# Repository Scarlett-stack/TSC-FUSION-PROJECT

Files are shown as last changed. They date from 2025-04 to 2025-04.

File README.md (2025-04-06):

# TSC-FUSION-PROJECT
Ebook project TSC 2025
## Schema bloc


## BOM
| Componentă | Link sursă | Datasheet |
|---|---|---|
| BME680 | [SnapEDA](https://www.snapeda.com/parts/BME680/Bosch/view-part/?welcome=home) | [Datasheet](https://www.snapeda.com/parts/BME680/Bosch%20Sensortec/datasheet/) |
| CC0402MRX5R5BB106 | [ComponentSearchEngine](https://componentsearchengine.com/part-view/CC0402MRX5R5BB106/YAGEO) | [Datasheet](https://componentsearchengine.com/Datasheets/2/CC0402MRX5R5BB106.pdf) |
| DMG2305UX-7 | [ComponentSearchEngine](https://componentsearchengine.com/part-view/DMG2305UX-7/Diodes%20Incorporated) | [Datasheet](https://www.diodes.com//assets/Datasheets/DMG2305UX.pdf) |
| Varistor B72520T0350K062 | [Mouser](https://www.mouser.co.uk/ProductDetail/EPCOS-TDK/B72520T0350K062?qs=dEfas%2FXlABIszF52uu7vrg%3D%3D) | [Datasheet](https://www.tdk-electronics.tdk.com/inf/75/db/CTVS_14/Surge_protection_series.pdf) |
| FH34SRJ-24S-0.5SH_99_ | [ComponentSearchEngine](https://componentsearchengine.com/part-view/XC6220A331MR-G/Torex) | [Datasheet](https://product.torexsemi.com/system/files/series/xc6220.pdf) |
| MAX17048G+T10 | [SnapEDA](https://www.snapeda.com/parts/MAX17048G+T10/Analog+Devices/view-part/?ref=eda) | [Datasheet](https://www.snapeda.com/parts/MAX17048G+T10/Analog%20Devices/datasheet/) |
| MBR0530 | [Mouser](https://ro.mouser.com/ProductDetail/KYOCERA-AVX/SD0805S020S1R0?qs=jCA%252BPfw4LHbpkAoSnwrdjw%3D%3D) | [Datasheet](https://ro.mouser.com/datasheet/2/40/schottky-3165252.pdf) |
| PGB1010603MR | [SnapEDA](https://www.snapeda.com/parts/PGB1010603MR/Littelfuse/view-part/?ref=eda) | [Datasheet](https://www.snapeda.com/parts/PGB1010603MR/Littelfuse%20Inc./datasheet/) |
| TR3B106K025C1300 | [Mouser](https://ro.mouser.com/ProductDetail/Vishay-Sprague/TR3B106K025C1300?qs=jCGqFXxTmLdffnuDkXzk1g%3D%3D) | [Datasheet](https://www.vishay.com/docs/40080/tr3.pdf) |
| USB4110-GF-A | [ComponentSearchEngine](https://componentsearchengine.com/part-view/USB4110-GF-A/GCT%20(GLOBAL%20CONNECTOR%20TECHNOLOGY)) | [Datasheet](https://gct.co/files/drawings/usb4110.pdf) |
| SI1308EDL-T1-GE3 | [ComponentSearchEngine](https://componentsearchengine.com/part-view/SI1308EDL-T1-GE3/Vishay) | [Datasheet](https://componentsearchengine.com/Datasheets/1/SI1308EDL-T1-GE3.pdf) |
| Solder Jumper (SJ) | [GrabCAD](https://grabcad.com/library/solder-jumpers-1) | — |
| USBLC6-2SC6Y | [SnapEDA](https://www.snapeda.com/parts/USBLC6-2SC6Y/STMicroelectronics/view-part/?ref=eda) | [Datasheet](https://www.snapeda.com/parts/USBLC6-2SC6Y/STMicroelectronics/datasheet/) |
| W25Q512JVEIQ | [SnapEDA](https://www.snapeda.com/parts/W25Q512JVEIQ/Winbond+Electronics/view-part/?ref=eda) | [Datasheet](https://www.snapeda.com/parts/W25Q512JVEIQ/Winbond%20Electronics/datasheet/) |
| XC6220A331MR-G | [ComponentSearchEngine](https://componentsearchengine.com/part-view/XC6220A331MR-G/Torex) | [Datasheet](https://product.torexsemi.com/system/files/series/xc6220.pdf) |
| RC0402FR-07226RL | [SnapEDA](https://www.snapeda.com/parts/RC0402FR-07226RL/Yageo/view-part/) | [Datasheet](https://www.snapeda.com/parts/RC0402FR-07226RL/Yageo/datasheet/) |
| QWIIC PRT-14417 | [SnapEDA](https://www.snapeda.com/parts/PRT-14417/SparkFun/view-part/) | [Datasheet](https://www.snapeda.com/parts/PRT-14417/SparkFun%20Electronics/datasheet/) |
| BUTTON EVQPUJ02K | [Panasonic](https://industry.panasonic.com/global/en/downloads?tab=cad&small_g_cd=203&part_no=EVQPUJ02K) | [Datasheet](https://industry.panasonic.com/global/en/downloads?tab=catalog&small_g_cd=203&part_no=EVQPUJ02K) |
| CPH3225A | [SnapEDA](https://www.snapeda.com/parts/CPH3225A/Seiko+Instruments/view-part/?ref=eda) | [Datasheet](https://www.snapeda.com/parts/CPH3225A/Seiko%20Instruments/datasheet/) |
| KP-1608SURCK (LED 0603) | [SnapEDA](https://www.snapeda.com/parts/KP-1608SURCK/Kingbright/view-part/?ref=search&t=LED%200603) | [Datasheet](https://www.snapeda.com/parts/KP-1608SURCK/Kingbright/datasheet/) |
| 112A-TAAR-R03_ATTEND | [Comet](https://store.comet.bg/en/Catalogue/Product/43497/) | [Datasheet](https://store.comet.bg/en/Catalogue/Product/43497/) |
| 744043680 | [DigiKey](https://www.digikey.sg/en/models/1638515) | [Datasheet](https://www.we-online.com/components/products/datasheet/744043680.pdf) |
| BD5229G-TR | [ComponentSearchEngine](https://componentsearchengine.com/part-view/BD5229G-TR/ROHM%20Semiconductor) | [Datasheet](https://datasheet.datasheetarchive.com/originals/distributors/Datasheets_SAMA/f2b9741ef86007909f138d561a359946.pdf) |
| DS3231SN# | [SnapEDA](https://www.snapeda.com/parts/DS3231SN%23/Analog+Devices/view-part/?ref=eda) | [Datasheet](https://www.snapeda.com/parts/DS3231SN%23/Analog%20Devices/datasheet/) |
| ESP32-C6-WROOM-1-N8 | [SnapEDA](https://www.snapeda.com/parts/ESP32-C6-WROOM-1-N8/Espressif+Systems/view-part/?ref=eda) | [Datasheet](https://www.snapeda.com/parts/ESP32-C6-WROOM-1-N8/Espressif%20Systems/datasheet/) |
| MCP73831 | [DigiKey](https://www.digikey.com/en/models/1874108) | — |
## Conexiuni ESP32-C6

| Funcționalitate | Pin ESP32-C6 | Descriere |
|---|---|---|
| UART pentru debug | TX/RX | Conectat la USB pentru programare si debug |
| I2C | IO4 (SCL), IO5 (SDA) | Utilizat pentru BME680, RTC și Qwiic connector |
| SPI | IO10 (CLK), IO11 (MOSI), IO12 (MISO), IO13 (CS) | Conexiune la memorie flash și display e-paper |
| Buton BOOT | IO9 | Conectat la reset/supervisor |
| LED / Status | IO6 | Indicator vizual |
| GPIO-uri libere | IO0, IO1, IO2, IO3 | Disponibile pentru extensii |

---

## Alimentare și Management Energie

- Alimentare principala: **3.7V Li-Po**
- Convertor LDO: **DMG2305UX** + **XC6220A331MR-G** — iesire 3.3V/300mA
- incarcare baterie: **MCP73831**
- Monitorizare baterie: **MAX17048**
- Protectie ESD: **USBLC6-2SC6Y** si protectii dedicate SPI

---

## Funcționalitate Hardware

- **ESP32-C6**: Procesor principal, suport Wi-Fi și BLE, interfata pentru toate componentele externe.
- **E-paper display**: Consum redusă.
- **Senzor de mediu BME680**: Citiri de temperatura, umiditate și calitate aer.
- **DS3231SN**: Ceas de timp real cu baterie de rezerva.
- **Memorie externă W25Q512JVEIQ**: 64MB pentru carti, setari etc.
- **MAX17048**: Estimare precisa a nivelului bateriei.
- **Interfete QWIIC / SPI / I2C** pentru extensibilitate și modularitate.

---

## Imagini PCB

Vezi folderul Images pt detalii

---

## Alte observații

- PCB-ul este în format Eagle, dimensiune compactă
- Conector USB-C cu protecții ESD
- Buton BOOT și RESET integrate
- Jumperi pentru configurare de test/debug
- Test Pads pentru depanare rapida

---
Am acceptat erorile SMD de overlap pt ca asa ni s-a zis la curs

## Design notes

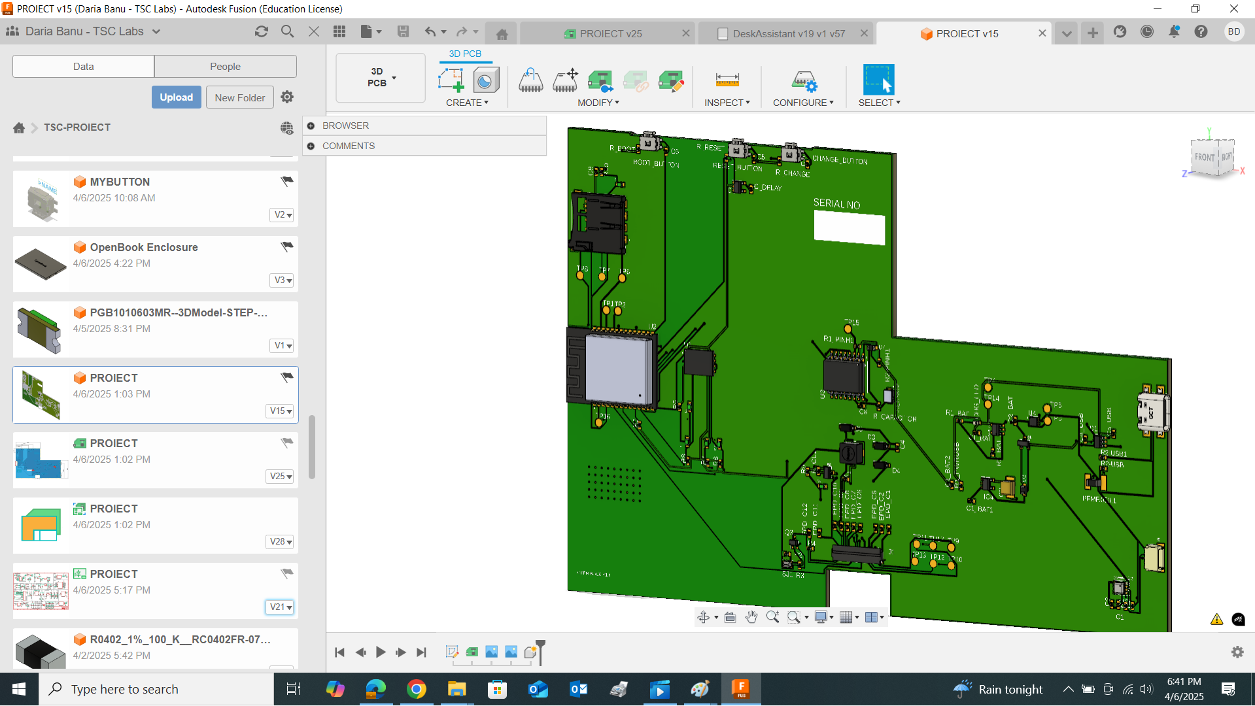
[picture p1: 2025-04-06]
Images/pcb-3d.png

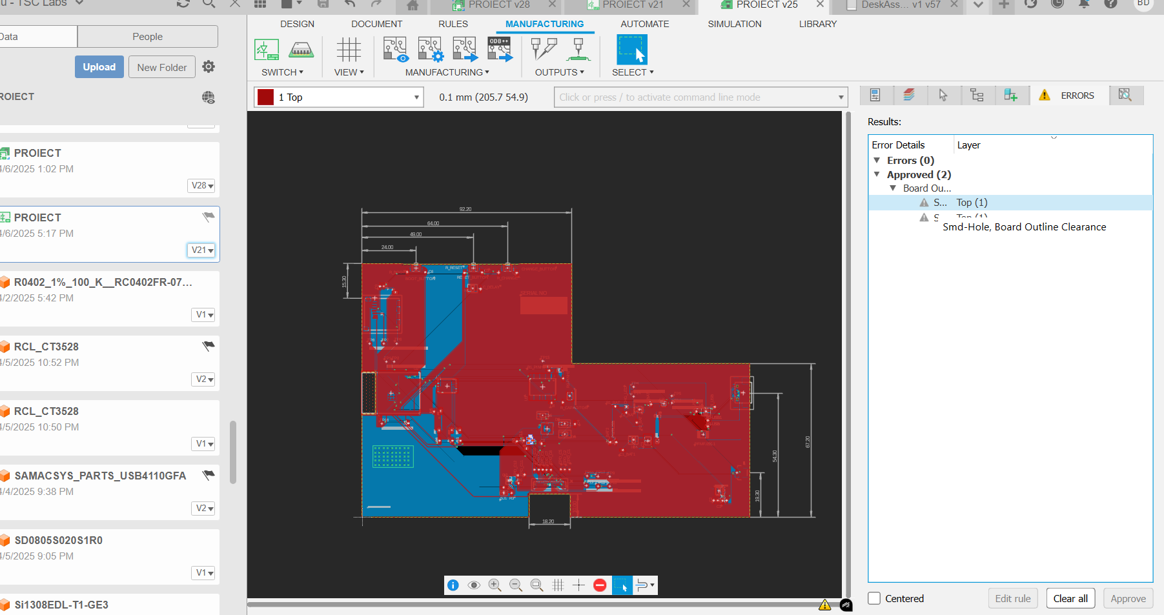
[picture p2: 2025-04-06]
Images/pcb-plan-masa.png

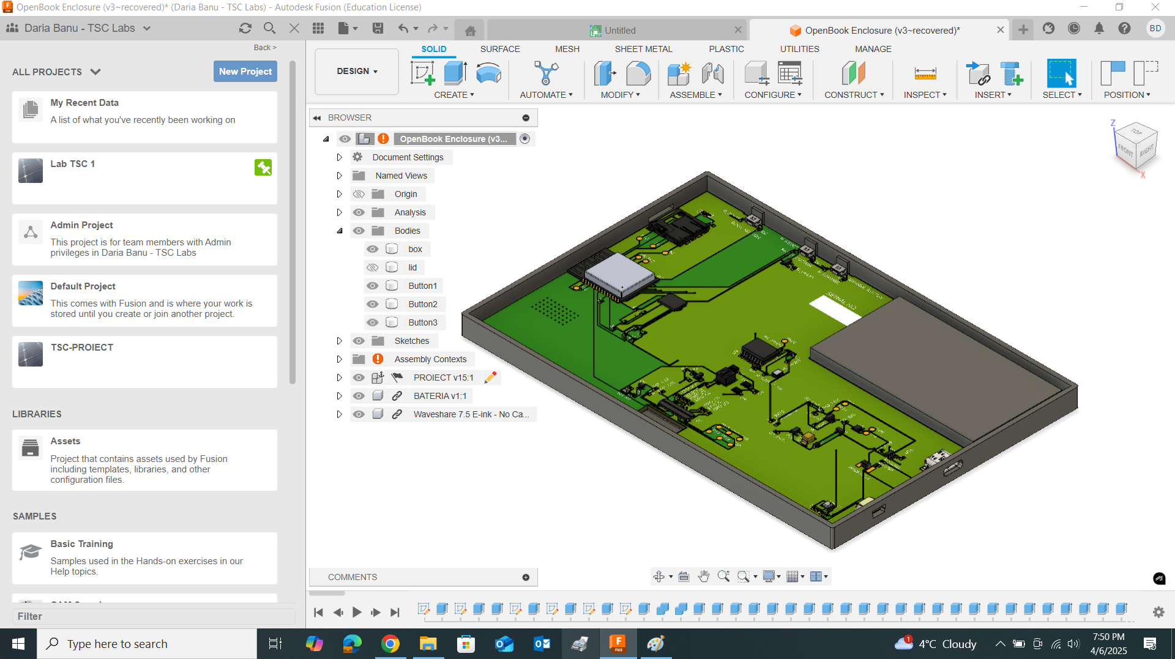
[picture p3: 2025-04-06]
Images/pcb-in-carcasa.png

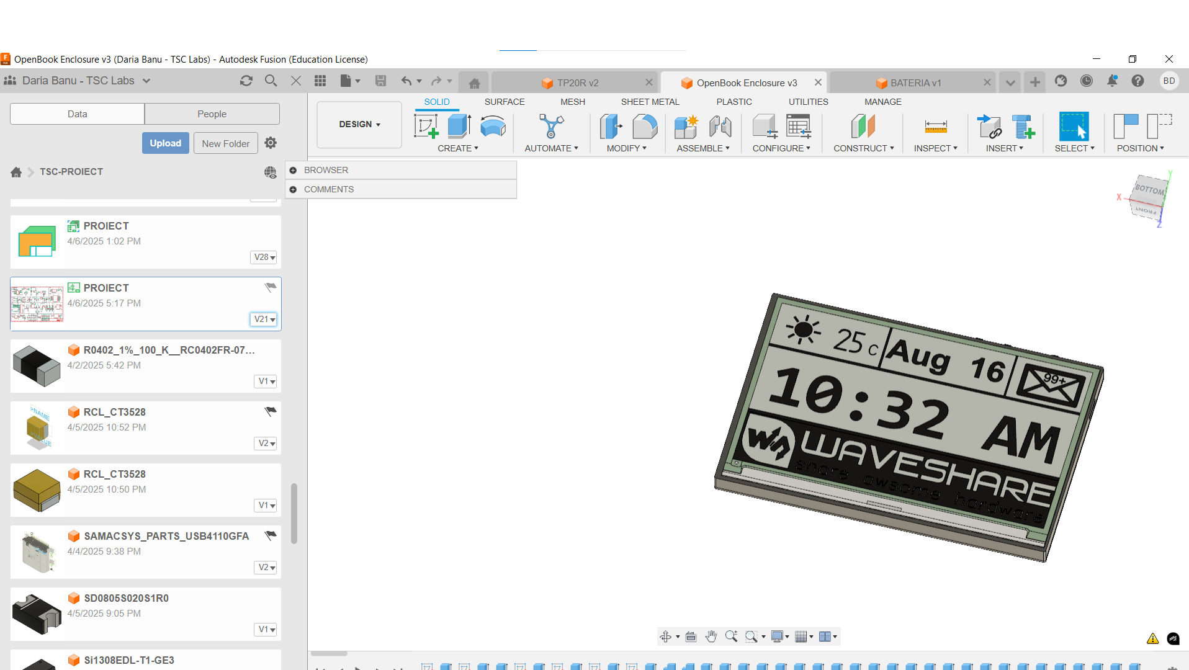
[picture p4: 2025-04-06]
Images/final_ebookreader.png

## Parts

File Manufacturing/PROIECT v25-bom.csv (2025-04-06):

Qty | Value | Device | Package | Parts | Description | ARROW_PART_NUMBER | ARROW_PRICE-STOCK | AVAILABILITY | CHECK_PRICES | DESCRIPTION | HEIGHT | MANUFACTURER_NAME | MANUFACTURER_PART_NUMBER | MF | MOUSER_PART_NUMBER | MOUSER_PRICE-STOCK | MOUSER_TESTING_PART_NUMBER | MOUSER_TESTING_PRICE-STOCK | MP | NUME | PACKAGE | PRICE | Q2 | SNAPEDA_LINK
1 |  | ADAFRUIT_LEDCHIP-LED0603 | ADAFRUIT_CHIP-LED0603 | CHG_LED | LED
1 |  | SJ. | SJ | SJ1 | SMD solder JUMPER
1 | 0.1uF/50V | EAGLE-LTSPICE_CC0402 | EAGLE-LTSPICE_C0402 | EPD_C5 | CAPACITOR, European symbol
1 | 0.47 | ESP32_WROVER_EAGLE-LTSPICE_RR0402 | ESP32_WROVER_EAGLE-LTSPICE_R0402 | R3 | RESISTOR, European symbol
1 | 100K | ESP32_WROVER_EAGLE-LTSPICE_RR0402 | ESP32_WROVER_EAGLE-LTSPICE_R0402 | R1_PWRUSB | RESISTOR, European symbol
8 | 100nF | EAGLE-LTSPICE_CC0402 | EAGLE-LTSPICE_C0402 | C1, C2, C4_USB, C6, C8, C9, C10, C_DELAY | CAPACITOR, European symbol
1 | 100uF TANT | RCL_CPOL-EUCT3528 | RCL_CT3528 | C3 | POLARIZED CAPACITOR, European symbol
16 | 10K | ESP32_WROVER_EAGLE-LTSPICE_RR0402 | ESP32_WROVER_EAGLE-LTSPICE_R0402 | R1, R1_PINH, R1_PINH1, R2-PINH, R2-PINH1, R4, R5, R6, R7, R8, R9, R10, R_BOOT, R_CHANGE, R_CL1, R_RESET | RESISTOR, European symbol
1 | 10uF | EAGLE-LTSPICE_CC0402 | EAGLE-LTSPICE_C0402 | C7 | CAPACITOR, European symbol
1 | 112A-TAAR-R03_ATTEND | 112A-TAAR-R03_ATTEND | 112ATAARR03ATTEND | J4 | Micro SD Card Socket, Push-Push Type, Top Mount, SMT, H=1.83mm, 10u |  |  |  |  | Micro SD Card Socket | Push-Push Type | Top Mount | SMT | H=1.83mm | 10u | 1.9mm | ATTEND | 112A-TAAR-R03 ATTEND
1 | 15 | ESP32_WROVER_EAGLE-LTSPICE_RR0402 | ESP32_WROVER_EAGLE-LTSPICE_R0402 | R_CAPACITOR | RESISTOR, European symbol
1 | 1uF | EAGLE-LTSPICE_CC0402 | EAGLE-LTSPICE_C0402 | C5 | CAPACITOR, European symbol
9 | 1uF/50V | EAGLE-LTSPICE_CC0402 | EAGLE-LTSPICE_C0402 | EPD_C1, EPD_C2, EPD_C6, EPD_C7, EPD_C8, EPD_C9, EPD_C10, EPD_C11, EPD_C12 | CAPACITOR, European symbol
1 | 2.2 | ESP32_WROVER_EAGLE-LTSPICE_RR0402 | ESP32_WROVER_EAGLE-LTSPICE_R0402 | R2 | RESISTOR, European symbol
1 | 200 | ESP32_WROVER_EAGLE-LTSPICE_RR0402 | ESP32_WROVER_EAGLE-LTSPICE_R0402 | R1_BAT | RESISTOR, European symbol
1 | 20V/4.2A/52mO/1.4W | ESP32_WROVER_SPARKFUN-DISCRETESEMI_MOSFET_PCH-DMG2305UX-7 | ESP32_WROVER_SPARKFUN-DISCRETESEMI_SOT23-3 | Q2 | P-channel MOSFETs |  |  |  |  |  |  |  |  |  |  |  |  |  |  |  |  |  | DMG2305UX-7
1 | 20V/4.2A/52mO/1.4W | ESP32_WROVER_SPARKFUN-DISCRETESEMI_MOSFET_PCH-DMG2305UX-7 | ESP32_WROVER_SPARKFUN-DISCRETESEMI_SOT23-3 | Q1 | P-channel MOSFETs |  |  |  |  |  |  |  |  |  |  |  |  |  |  | DMG2305UX-7
1 | 2K | ESP32_WROVER_EAGLE-LTSPICE_RR0402 | ESP32_WROVER_EAGLE-LTSPICE_R0402 | R2_BAT | RESISTOR, European symbol
5 | 4.7uF | EAGLE-LTSPICE_CC0402 | EAGLE-LTSPICE_C0402 | C1_BAT, C1_BAT1, C1_BAT2, C2_BAT, C5_USB | CAPACITOR, European symbol
1 | 4.7uF/25V | EAGLE-LTSPICE_CC0402 | EAGLE-LTSPICE_C0402 | C4 | CAPACITOR, European symbol
2 | 5k1 | ESP32_WROVER_EAGLE-LTSPICE_RR0402 | ESP32_WROVER_EAGLE-LTSPICE_R0402 | R2-USB, R2-USB1 | RESISTOR, European symbol
1 | 68uH | 744043680IND_4828-WE-TPC_WRE | IND_4828-WE-TPC_WRE | L1
1 | BD5229G-TR. | BD5229G-TR. | SOT95P280X125-5N | IC1 | Voltage Detector with Adjustable Delay Time: CMOS processes are utilized to develop high precision, low current consumption CMOS reset ICs that allow arbitrary setting of the delay time. The extensive lineup includes both Nch Open Drain and CMOS output types in a wide range of detection voltages (from 2.3V to 6.0V, in 0.1V steps), enabling selection of the ideal solution based on customer requirements. In addition, the entire series is of course both lead-free and RoHS-compliant.
3 | BUTTON_CUSYOMV1. | BUTTON_CUSYOMV1. | MYBUTTON | BOOT_BUTTON, CHANGE_BUTTON, RESET_BUTTON
1 | CPH3225A. | CPH3225A. | CAPCP3225X100N | C10_SUPERCAP | Cap 0.011F 3.3V 1210 Flat Check availability
1 | DS3231SN#. | DS3231SN#. | SOIC127P1032X265-16N | U3 | Real Time Clock Serial 16-Pin SOIC W T/R Check availability
1 | ESP32-C6-WROOM-1-N8 | ESP32-C6-WROOM-1-N8 | XCVR_ESP32-C6-WROOM-1-N8 | U2 | Check availability |  |  | In Stock | https://www.snapeda.com/parts/ESP32-C6-WROOM-1-N8/Espressif+Systems/view-part/?ref=eda | Multiprotocol Modules ESP32-C6 module | Wi-Fi 6 in 2.4 GHz band | Bluetooth 5 | Zigbee 3.0 and Thread. ESP34-WROOM Compatible - ENGINEERING SAMPLE |  |  |  | Espressif Systems |  |  |  |  | ESP32-C6-WROOM-1-N8 |  | None
1 | ESP32C6_VARISTORCN1812 | ESP32C6_VARISTORCN1812 | ESP32C6_VARISTOR_CT/CN1812 | PFMF.050.1 | VARISTOR
2 | ESP32_WROVER_AVX---SD0805S020S1R0_AVX_SD0805S020S1R0_0_0AVX_SD0805S020S1R0_0_0 | ESP32_WROVER_AVX---SD0805S020S1R0_AVX_SD0805S020S1R0_0_0AVX_SD0805S020S1R0_0_0 | ESP32_WROVER_AVX---SD0805S020S1R0_AVX_SD0805S020S1R0_0 | D2, D7 | Schottky Barrier Rectifier Diode |  |  |  |  |  |  |  |  |  |  |  |  |  |  | SD0805S020S1R0
1 | ESP32_WROVER_BME680_BME680. | ESP32_WROVER_BME680_BME680. | ESP32_WROVER_BME680_PSON80P300X300X100-8N | SENSOR2 | Integrated Environmental Unit |  |  |  |  |  |  |  |  |  |  |  |  |  |  | BME688
1 | ESP32_WROVER_SPARKFUN-IC-POWER_MCP73831. | ESP32_WROVER_SPARKFUN-IC-POWER_MCP73831. | ESP32_WROVER_SPARKFUN-IC-POWER_SOT23-5 | MCP73831 | MCP73831T Li-Ion, Li-Pol Controller
1 | FH34SRJ-24S-0.5SH_99_. | FH34SRJ-24S-0.5SH_99_. | FH34SRJ24S05SH99 | J1 | (0.50mm) Surface Mount, Right Angle
1 | MAX17048G+T10. | MAX17048G+T10. | SON50P200X200X80-9N | U4 | Check availability
3 | MBR0530. | MBR0530. | SOD3716X135N | D3, D4, D5 | ON SEMICONDUCTOR - MBR0530 - DIODE, SCHOTTKY, 0.5A, 30V, SOD-123
6 | PGB1010603MR. | PGB1010603MR. | DIOC1608X36N | D6, D8, D9, D10, D11, D12 | Check availability
1 | QWIIC_RIGHT_ANGLE | QWIIC_CONNECTORJS-1MM | JST04_1MM_RA | J3 | SparkFun I2C Standard Qwiic Connector
1 | SAMACSYS_PARTS_USB4110-GF-ASAMA | SAMACSYS_PARTS_USB4110-GF-ASAMA | SAMACSYS_PARTS_USB4110GFA | J2 | CONN USB 2.0 TYPE-C R/A SMT
1 | SI1308EDL-T1-GE3. | SI1308EDL-T1-GE3. | SOT65P210X110-3N | Q3 | MOSFET N-Ch 30V 1.5A TrenchFET SC70 Vishay Si1308EDL-T1-GE3 N-channel MOSFET Transistor, 1.5 A, 30 V, 3-Pin SC-70
17 | TPTP20R | TPTP20R | TP20R | TP1, TP2, TP3, TP4, TP5, TP6, TP7, TP8, TP9, TP10, TP11, TP12, TP13, TP14, TP15, TP16, TP17 | Test pad
1 | USBLC6-2SC6Y. | USBLC6-2SC6Y. | SOT95P280X145-6N | D1 | Low Cap. ESD Protection Auto SOT-23-6 STMicroelectronics USBLC6-2SC6Y, Dual Uni-Directional TVS Diode Array, 6-Pin SOT-23
1 | W25Q512JVEIQ | W25Q512JVEIQ | SON127P600X800X80-9N | U1 | Check availability |  |  | In Stock | https://www.snapeda.com/parts/W25Q512JVEIQ/Winbond+Electronics/view-part/?ref=eda | FLASH - NOR Memory IC 512Mb (64M x 8) SPI - Quad I/O 133 MHz 8-WSON (8x6) |  |  |  | Winbond Electronics |  |  |  |  | W25Q512JVEIQ |  | Package | None |  | https://www.snapeda.com/parts/W25Q512JVEIQ/Winbond+Electronics/view-part/?ref=snap
1 | XC6220A331MR-G. | XC6220A331MR-G. | SOT95P280X120-5N | IC4 | LDO Voltage Regulators

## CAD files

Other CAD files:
Mechanical/OpenBook Enclosure v6.f3z

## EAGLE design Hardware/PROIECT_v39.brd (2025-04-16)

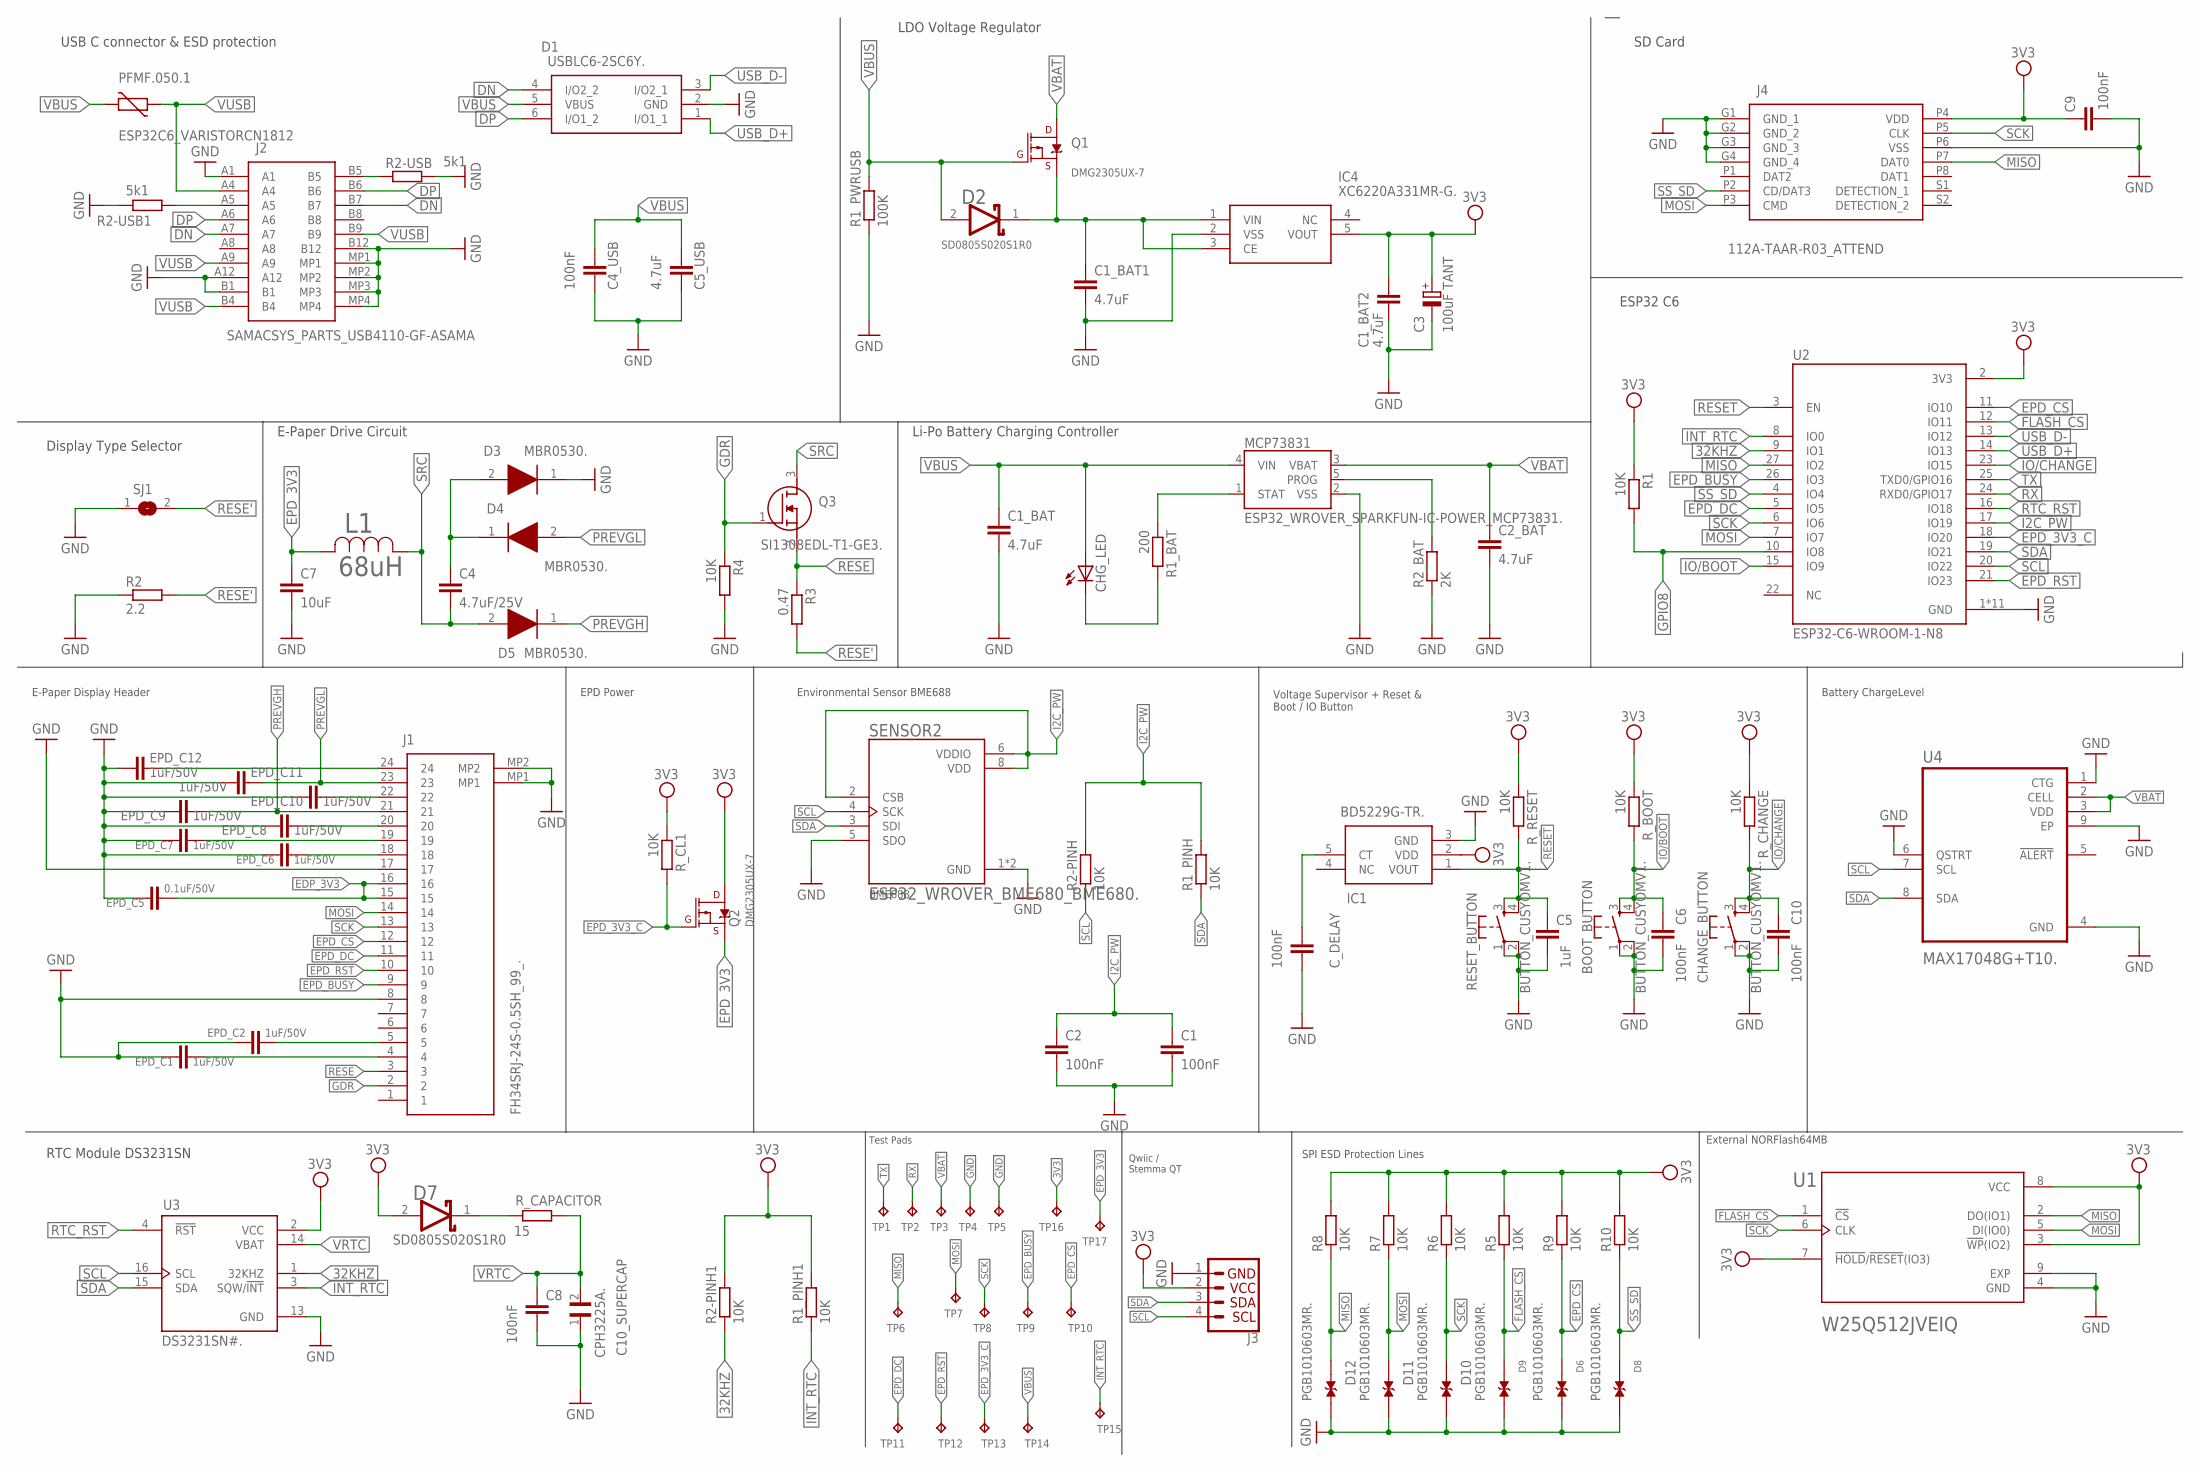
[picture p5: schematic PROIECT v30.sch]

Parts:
BOOT_BUTTON: BUTTON_CUSYOMV1.; MYBUTTON
C1, C2, C4_USB, C6, C8, C9, C10: 100nF; EAGLE-LTSPICE_C0402
C1_BAT, C1_BAT1, C1_BAT2, C2_BAT, C5_USB: 4.7uF; EAGLE-LTSPICE_C0402
C3: 100uF TANT; RCL_CT3528
C4: 4.7uF/25V; EAGLE-LTSPICE_C0402
C5: 1uF; EAGLE-LTSPICE_C0402
C7: 10uF; EAGLE-LTSPICE_C0402
C10_SUPERCAP: CPH3225A.; CAPCP3225X100N
CHANGE_BUTTON: BUTTON_CUSYOMV1.; MYBUTTON
CHG_LED: ADAFRUIT_LEDCHIP-LED0603; ADAFRUIT_CHIP-LED0603
C_DELAY: 100nF; EAGLE-LTSPICE_C0402
D1: USBLC6-2SC6Y.; SOT95P280X145-6N
D2, D7: ESP32_WROVER_AVX---SD0805S020S1R0_AVX_SD0805S020S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; ESP32_WROVER_AVX---SD0805S020S1R0_AVX_SD0805S020S1R0_0
D3, D4, D5: MBR0530.; SOD3716X135N
D6, D8, D9, D10, D11, D12: PGB1010603MR.; DIOC1608X36N
EPD_C1, EPD_C2, EPD_C6, EPD_C7, EPD_C8, EPD_C9, EPD_C10, EPD_C11, EPD_C12: 1uF/50V; EAGLE-LTSPICE_C0402
EPD_C5: 0.1uF/50V; EAGLE-LTSPICE_C0402
IC1: BD5229G-TR.; SOT95P280X125-5N
IC4: XC6220A331MR-G.; SOT95P280X120-5N
J1: FH34SRJ-24S-0.5SH_99_.; FH34SRJ24S05SH99
J2: SAMACSYS_PARTS_USB4110-GF-ASAMA; SAMACSYS_PARTS_USB4110GFA
J3: QWIIC_RIGHT_ANGLE; JST04_1MM_RA
J4: 112A-TAAR-R03_ATTEND; 112ATAARR03ATTEND
L1: 68uH; IND_4828-WE-TPC_WRE
MCP73831: ESP32_WROVER_SPARKFUN-IC-POWER_MCP73831.; ESP32_WROVER_SPARKFUN-IC-POWER_SOT23-5
PFMF.050.1: ESP32C6_VARISTORCN1812; ESP32C6_VARISTOR_CT/CN1812
Q1, Q2: 20V/4.2A/52mΩ/1.4W; ESP32_WROVER_SPARKFUN-DISCRETESEMI_SOT23-3
Q3: SI1308EDL-T1-GE3.; SOT65P210X110-3N
R1, R1_PINH, R1_PINH1, R2-PINH, R2-PINH1, R4, R5, R6, R7, R8, R9, R10: 10K; ESP32_WROVER_EAGLE-LTSPICE_R0402
R1_BAT: 200; ESP32_WROVER_EAGLE-LTSPICE_R0402
R1_PWRUSB: 100K; ESP32_WROVER_EAGLE-LTSPICE_R0402
R2: 2.2; ESP32_WROVER_EAGLE-LTSPICE_R0402
R2-USB, R2-USB1: 5k1; ESP32_WROVER_EAGLE-LTSPICE_R0402
R2_BAT: 2K; ESP32_WROVER_EAGLE-LTSPICE_R0402
R3: 0.47; ESP32_WROVER_EAGLE-LTSPICE_R0402
RESET_BUTTON: BUTTON_CUSYOMV1.; MYBUTTON
R_BOOT: 10K; ESP32_WROVER_EAGLE-LTSPICE_R0402
R_CAPACITOR: 15; ESP32_WROVER_EAGLE-LTSPICE_R0402
R_CHANGE: 10K; ESP32_WROVER_EAGLE-LTSPICE_R0402
R_CL1: 10K; ESP32_WROVER_EAGLE-LTSPICE_R0402
R_RESET: 10K; ESP32_WROVER_EAGLE-LTSPICE_R0402
SENSOR2: ESP32_WROVER_BME680_BME680.; ESP32_WROVER_BME680_PSON80P300X300X100-8N
SJ1: SJ.; SJ
TP1, TP2, TP3, TP4, TP5, TP6, TP7, TP8, TP9, TP10, TP11, TP12, TP13, TP14, TP15, TP16, TP17: TPTP20R; TP20R
U1: W25Q512JVEIQ; SON127P600X800X80-9N
U2: ESP32-C6-WROOM-1-N8; XCVR_ESP32-C6-WROOM-1-N8
U3: DS3231SN#.; SOIC127P1032X265-16N
U4: MAX17048G+T10.; SON50P200X200X80-9N

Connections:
3V3: C1_BAT2.1, C3.+, C9.1, D7.2 (ANODE), IC1.2 (VDD), IC4.5 (VOUT), J3.2, J4.P4 (VDD), Q2.3 (D), R1.1, R1_PINH1.2, R2-PINH1.2, R5.2, R6.2, R7.2, R8.2, R9.2, R10.2, R_BOOT.1, R_CHANGE.1, R_CL1.1, R_RESET.1, TP16.TP, U1.3 (!WP!(IO2)), U1.7 (!HOLD!/!RESET!(IO3)), U1.8 (VCC), U2.2 (3V3), U3.2 (VCC)
32KHZ: R2-PINH1.1, U2.9 (IO1), U3.1 (32KHZ)
DN: D1.4 (I/O2_2), J2.A7, J2.B7
DP: D1.6 (I/O1_2), J2.A6, J2.B6
EDP_3V3: EPD_C5.1, J1.15, J1.16
EPD_3V3: C7.1, L1.2, Q2.2 (S), TP17.TP
EPD_3V3_C: Q2.1 (G), R_CL1.2, TP13.TP, U2.18 (IO20)
EPD_BUSY: J1.9, TP9.TP, U2.26 (IO3)
EPD_CS: D6.1, J1.12, R9.1, TP10.TP, U2.11 (IO10)
EPD_DC: J1.11, TP11.TP, U2.5 (IO5)
EPD_RST: J1.10, TP12.TP, U2.21 (IO23)
FLASH_CS: D9.1, R5.1, U1.1 (!CS), U2.12 (IO11)
GDR: J1.2, Q3.1 (G), R4.1
GND: BOOT_BUTTON.1, BOOT_BUTTON.2, C1.2, C1_BAT.2, C1_BAT1.2, C1_BAT2.2, C2.2, C2_BAT.2, C3.-, C4_USB.2, C5.2, C5_USB.2, C6.2, C7.2, C8.2, C9.2, C10.2, C10_SUPERCAP.1, CHANGE_BUTTON.1, CHANGE_BUTTON.2, C_DELAY.2, D1.2 (GND), D3.1 (K), D6.2, D8.2, D9.2, D10.2, D11.2, D12.2, EPD_C1.2, EPD_C2.2, EPD_C5.2, EPD_C6.2, EPD_C7.2, EPD_C8.2, EPD_C9.2, EPD_C10.2, EPD_C11.2, EPD_C12.2, IC1.3 (GND), IC4.2 (VSS), J1.8, J1.17, J1.MP1, J1.MP2, J2.A1, J2.A12, J2.B1, J2.B12, J2.MP1, J2.MP2, J2.MP3, J2.MP4, J3.1, J4.G1 (GND_1), J4.G2 (GND_2), J4.G3 (GND_3), J4.G4 (GND_4), J4.P6 (VSS), MCP73831.2 (VSS), R1_PWRUSB.1, R2.1, R2-USB.2, R2-USB1.1, R2_BAT.1, R4.2, RESET_BUTTON.1, RESET_BUTTON.2, SENSOR2.1 (GND), SENSOR2.5 (SDO), SENSOR2.7 (GND), SJ1.1, TP4.TP, TP5.TP, U1.4 (GND), U1.9 (EXP), U2.1 (GND), U2.28 (GND), U2.29_1 (GND), U2.29_2 (GND), U2.29_3 (GND), U2.29_4 (GND), U2.29_5 (GND), U2.29_6 (GND), U2.29_7 (GND), U2.29_8 (GND), U2.29_9 (GND), U3.13 (GND), U4.1 (CTG), U4.4 (GND), U4.6 (QSTRT), U4.9 (EP)
GPIO8: R1.2, U2.10 (IO8)
I2C_PW: C1.1, C2.1, R1_PINH.2, R2-PINH.2, SENSOR2.2 (CSB), SENSOR2.6 (VDDIO), SENSOR2.8 (VDD), U2.17 (IO19)
INT_RTC: R1_PINH1.1, TP15.TP, U2.8 (IO0), U3.3 (SQW/!INT)
IO/BOOT: BOOT_BUTTON.3, BOOT_BUTTON.4, C6.1, R_BOOT.2, U2.15 (IO9)
IO/CHANGE: C10.1, CHANGE_BUTTON.3, CHANGE_BUTTON.4, R_CHANGE.2, U2.23 (IO15)
MISO: D12.1, J4.P7 (DAT0), R8.1, TP6.TP, U1.2 (DO(IO1)), U2.27 (IO2)
MOSI: D11.1, J1.14, J4.P3 (CMD), R7.1, TP7.TP, U1.5 (DI(IO0)), U2.7 (IO7)
unnamed: C1_BAT1.1, D2.1 (CATHODE), IC4.1 (VIN), IC4.3 (CE), Q1.2 (S)
unnamed: CHG_LED.C, R1_BAT.2
unnamed: MCP73831.1 (STAT), R1_BAT.1
unnamed: J2.A5, R2-USB1.2
unnamed: C4.1, D3.2 (A), D4.1 (K)
unnamed: EPD_C12.1, J1.24
unnamed: MCP73831.5 (PROG), R2_BAT.2
unnamed: EPD_C10.1, J1.22
unnamed: C_DELAY.1, IC1.5 (CT)
unnamed: EPD_C8.1, J1.20
unnamed: J2.B5, R2-USB.1
unnamed: EPD_C7.1, J1.19
unnamed: EPD_C6.1, J1.18
unnamed: EPD_C2.1, J1.5
unnamed: EPD_C1.1, J1.4
unnamed: D7.1 (CATHODE), R_CAPACITOR.2
PREVGH: D5.1 (K), EPD_C9.1, J1.21
PREVGL: D4.2 (A), EPD_C11.1, J1.23
RESE: J1.3, Q3.2 (S), R3.1
RESE': R2.2, R3.2, SJ1.2
RESET: C5.1, IC1.1 (VOUT), RESET_BUTTON.3, RESET_BUTTON.4, R_RESET.2, U2.3 (EN)
RTC_RST: U2.16 (IO18), U3.4 (!RST)
RX: TP2.TP, U2.24 (RXD0/GPIO17)
SCK: D10.1, J1.13, J4.P5 (CLK), R6.1, TP8.TP, U1.6 (CLK), U2.6 (IO6)
SCL: J3.4, R2-PINH.1, SENSOR2.4 (SCK), U2.20 (IO22), U3.16 (SCL), U4.7 (SCL)
SDA: J3.3, R1_PINH.1, SENSOR2.3 (SDI), U2.19 (IO21), U3.15 (SDA), U4.8 (SDA)
SRC: C4.2, D5.2 (A), L1.1, Q3.3 (D)
SS_SD: D8.1, J4.P2 (CD/DAT3), R10.1, U2.4 (IO4)
TX: TP1.TP, U2.25 (TXD0/GPIO16)
USB_D+: D1.1 (I/O1_1), U2.14 (IO13)
USB_D-: D1.3 (I/O2_1), U2.13 (IO12)
VBAT: C2_BAT.1, MCP73831.3 (VBAT), Q1.3 (D), TP3.TP, U4.2 (CELL), U4.3 (VDD)
VBUS: C1_BAT.1, C4_USB.1, C5_USB.1, CHG_LED.A, D1.5 (VBUS), D2.2 (ANODE), MCP73831.4 (VIN), PFMF.050.1.2, Q1.1 (G), R1_PWRUSB.2, TP14.TP
VRTC: C8.1, C10_SUPERCAP.2, R_CAPACITOR.1, U3.14 (VBAT)
VUSB: J2.A4, J2.A9, J2.B4, J2.B9, PFMF.050.1.1

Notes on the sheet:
SD Card
ESP32 C6
USB C connector & ESD protection
Display Type Selector
LDO Voltage Regulator
E-Paper Drive Circuit
Li-Po Battery Charging Controller
E-Paper Display Header
EPD Power
Environmental Sensor BME688
Voltage Supervisor + Reset & Boot / IO Button
Battery ChargeLevel
RTC Module DS3231SN
Test Pads
Qwiic / Stemma QT
SPI ESD Protection Lines
External NORFlash64MB

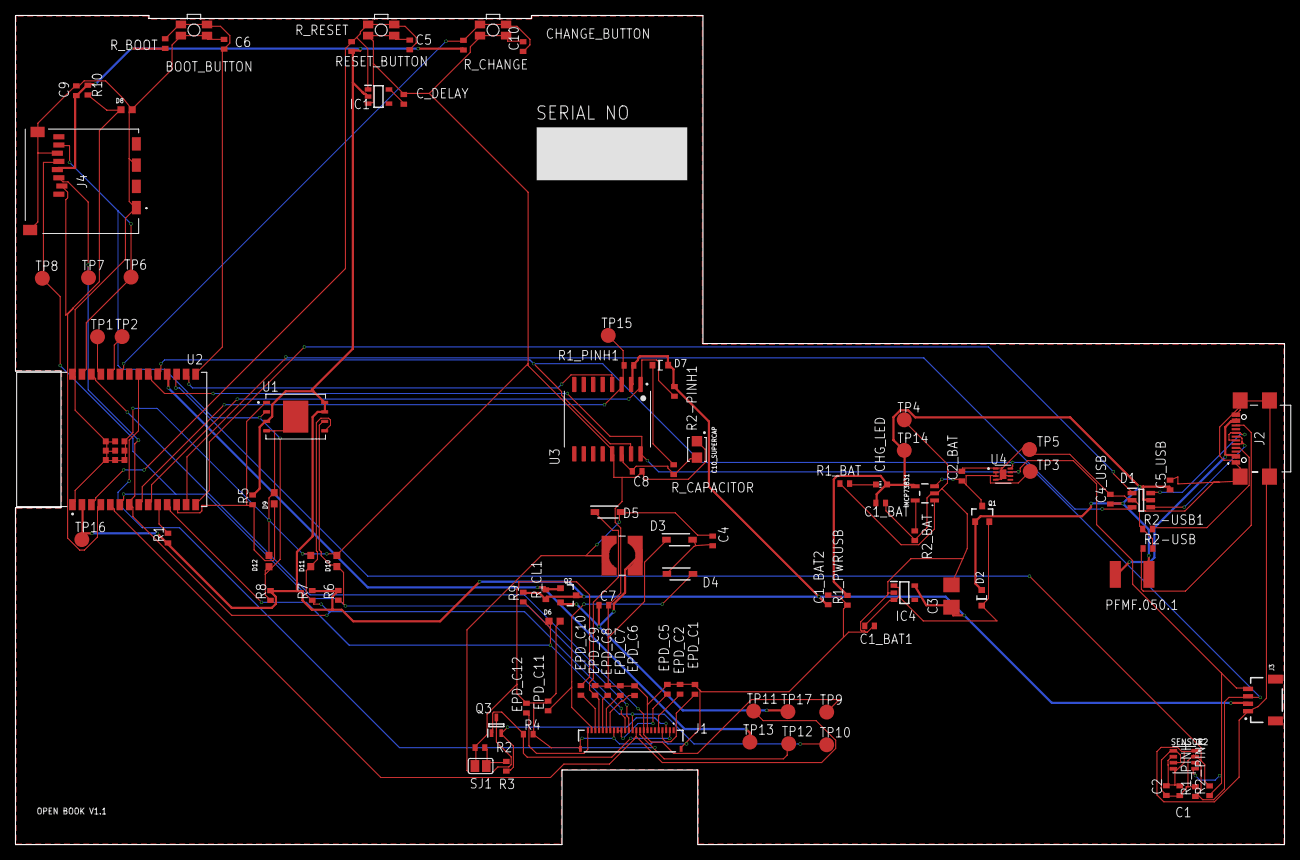
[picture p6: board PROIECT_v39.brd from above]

Board: 2 copper layers, 170.2 x 111.2 mm, 103 parts (0 on the bottom side), 56 nets.
